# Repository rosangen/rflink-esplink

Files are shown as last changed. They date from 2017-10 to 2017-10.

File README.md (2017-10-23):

RFLink-ESPLink pcb
===================

This is a PCB card for use with [RFLink](http://rflink.nl/blog2/) software, [ESP-Link](https://github.com/jeelabs/esp-link), [ESP-Easy](https://github.com/letscontrolit/ESPEasy) or what you find fits you best.
It is mainly for my purpose of getting [IKEA anslut remote control](http://www.ikea.com/se/sv/catalog/products/90300773/) in my Home Assistant setup. And for measure my pellets and power meter.

**You can fill the board so it meat yours need!!**

Use it as a RFLink with receiver and transmitter, and connect to server with USB, add CC2500 module for IKEA asnlut support.

Add a Wemos D1 Mini to get the RFLink more portable and communicate via WiFi via [tcp-mode](https://home-assistant.io/components/rflink/#tcp-mode).
If you just are interested in IKEA anslut, use a CC2500 module + Arduino Pro Mini + Wemos D1 Mini and communicate with MQTT.
 
Inspired by https://github.com/NDBCK/Ansluta-Remote-Controller for Arduino Pro Mini support, and also https://github.com/Genestealer/Home-Assistant-RFLink-Gateway-ESP8266 fore the komplete setup!

Schema
-----------
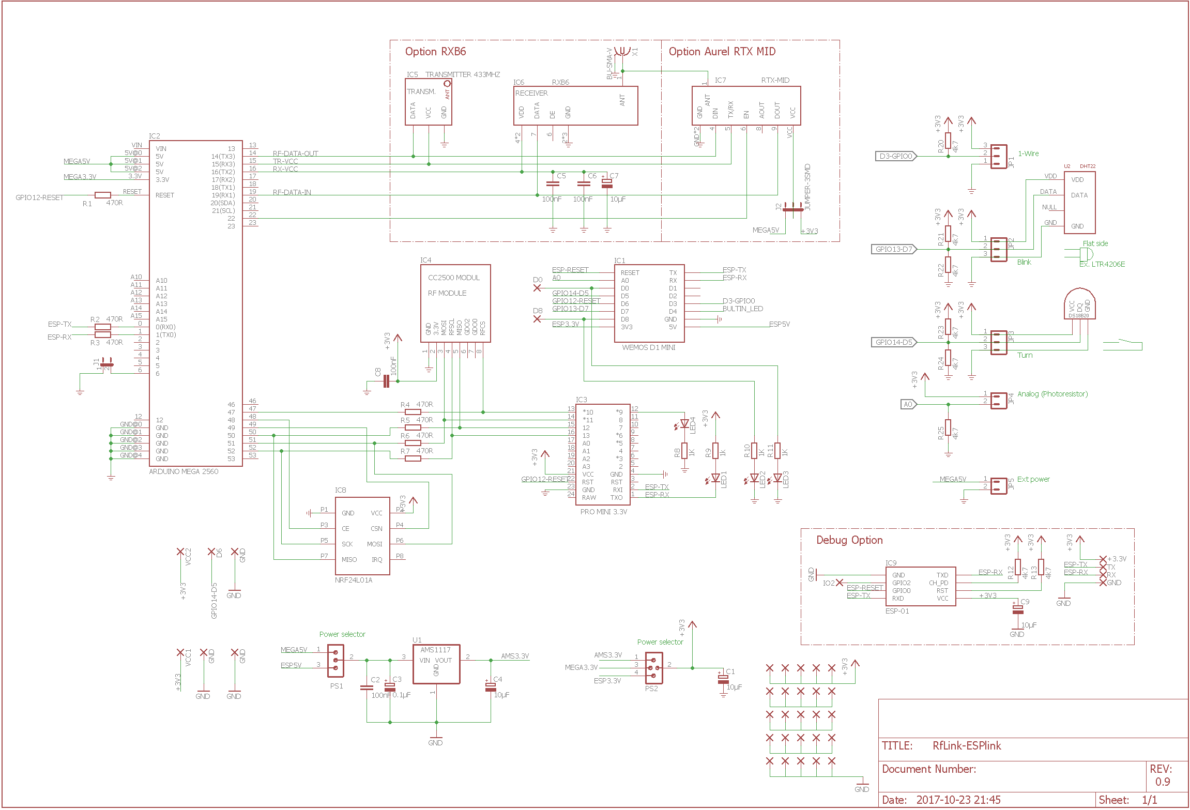
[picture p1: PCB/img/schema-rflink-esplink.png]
rflink-esplink schema Schema img

[Schema pdf](https://github.com/rosangen/rflink-esplink/blob/master/PCB/RfLink-ESPlink.pdf?raw=true "RfLink-ESPlink.pdf")

PCB
------
Size 94 x 96mm
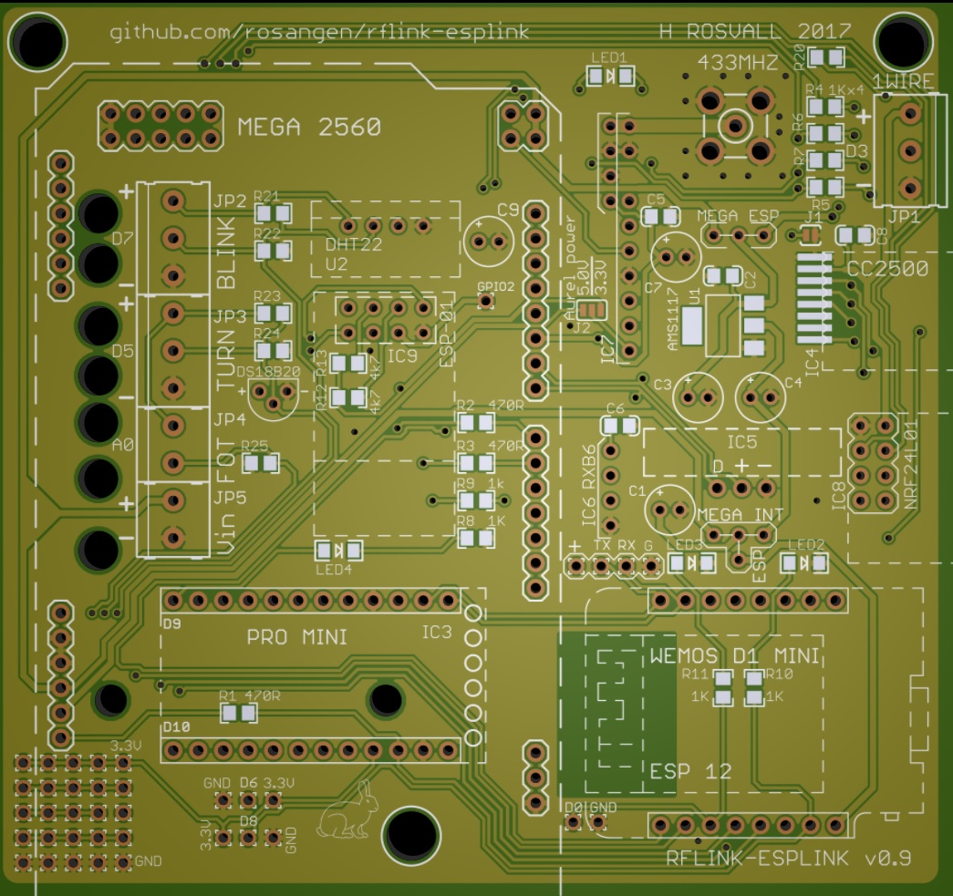
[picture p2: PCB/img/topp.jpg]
rflink-esplink pcb topside


Fore the moment, no PCB is tested, more info to come!

Configurations
-----------
Some configurations explained:

### RFLink USB connected:
```
IC2 Arduino Mega, IC5 Transmitter, IC6 or IC7 Receiver, X1 Antenna connection. 
Option 1: C5,C6 and C7 for better reception with RXB6 receiver.
Option 2: R3, R9, LED1 so se TX communication is visible (receiving data).
```

### RFLink with ESP-link:
```
IC1 ESP, IC2 Arduino Mega, IC5 Transmitter, IC6 or IC7 Receiver. R1, R2, R3.
- Ansluta option: IC4 CC2500, R4-7, C8.
- Option 1 and 2, se above.
```

### Anluta MQTT:
```
IC1 ESP, IC3 Arduino Pro Mini 3.3v, IC4 CC2500 modul, C8.
- Option R9 LED1
```

### EasyESP:
With 1-wire temp and power meter sensor.
```
IC1 ESP, R20-R25 if needed. If lead needed: R10, R11, LED 2, LED3, R20, JP1, R21, JP2. 
Temperatur: DS18B20 connected to JP1
Power meter: LTR4206E ir detector connected to JP2.
```

### Onboard 3.3v converter
If you don't want to use Mega 2560 or ESP interna 3.3v converter you can add U1 (AMS1117 3.3v) and C2, C3, C4.
- PS1 Power selector is for choose input source, IC2 Mega or IC1 ESP 5 volt. (JP5 can only be in used if not Mega 2560 is in use).
- PS2 is the 3.3v source selector, use INT with interna 3.3v converter.

Komponents
-----------

<table>
<tbody>
<tr>
<td><strong>Part</strong></td>
<td><strong>Value</strong></td>
<td><strong>Device/Type</strong></td>
<td><strong>Package/Info</strong></td>
</tr>
<tr>
<td>C1</td>
<td>10&micro;F</td>
<td>CAPACITOR</td>
<td>E2-5</td>
</tr>
<tr>
<td>C2</td>
<td>100nF</td>
<td>CAPACITOR</td>
<td>C0805</td>
</tr>
<tr>
<td>C3</td>
<td>0.1&micro;F</td>
<td>CAPACITOR</td>
<td>E2-5</td>
</tr>
<tr>
<td>C4</td>
<td>10&micro;F</td>
<td>CAPACITOR</td>
<td>E2-5</td>
</tr>
<tr>
<td>C5</td>
<td>100nF</td>
<td>CAPACITOR</td>
<td>C0805</td>
</tr>
<tr>
<td>C6</td>
<td>100nF</td>
<td>CAPACITOR</td>
<td>C0805</td>
</tr>
<tr>
<td>C7</td>
<td>10&micro;F</td>
<td>CPOL-EUE2-5</td>
<td>E2-5</td>
</tr>
<tr>
<td>C8</td>
<td>100nF</td>
<td>CAPACITOR</td>
<td>C0805</td>
</tr>
<tr>
<td>C9</td>
<td>10&micro;F</td>
<td>CPOL-EUE2-5</td>
<td>E2-5</td>
</tr>
<tr>
<td>IC1</td>
<td>WEMOS D1 MINI</td>
<td>WEMOS D1 MINI</td>
<td>&nbsp;WeMos.cc</td>
</tr>
<tr>
<td>IC2</td>
<td>ARDUINO-MEGA</td>
<td>ARDUINO MEGA 2560</td>
</tr>
<tr>
<td>IC3</td>
<td>PRO MINI 3.3V</td>
<td>ARDUINO PRO MINI</td>
</tr>
<tr>
<td>IC4</td>
<td>CC2500</td>
<td>CC2500 MODULE</td>
</tr>
<tr>
<td>IC5</td>
<td>TRANSMITTER 433MHZ</td>
<td>TRANSMITTER 433MHZ</td>
</tr>
<tr>
<td>IC6</td>
<td>RXB6</td>
<td>RECEIVER</td>
</tr>
<tr>
<td>IC7</td>
<td>RTX-MID</td>
<td>RTX-MID</td>
<td>Aurel</td>
</tr>
<tr>
<td>IC8</td>
<td>NRF24L01A</td>
<td>NRF24L01A</td>
<td>NRF24L01</td>
</tr>
<tr>
<td>IC9</td>
<td>ESP-01</td>
<td>ESP8266 Wifi module 01</td>
</tr>
<tr>
<td>J1</td>
<td>JUMPER 2 SMD</td>
<td>Jumper</td>
<td>Aktivate CC2500</td>
</tr>
<tr>
<td>J2</td>
<td>JUMPER 3 SMD</td>
<td>Jumper</td>
<td>3.3 or 5.0V Aurel</td>
</tr>
<tr>
<td>JP1</td>
<td>GS015S-3.81-3P</td>
<td>PCB terminal block</td>
<td>PCB terminal block</td>
</tr>
<tr>
<td>JP2</td>
<td>GS015S-3.81-3P</td>
<td>PCB terminal block</td>
<td>PCB terminal block</td>
</tr>
<tr>
<td>JP3</td>
<td>GS015S-3.81-3P</td>
<td>PCB terminal block</td>
<td>PCB terminal block</td>
</tr>
<tr>
<td>JP4</td>
<td>GS015S-3.81-2P</td>
<td>PCB terminal block</td>
<td>PCB terminal block</td>
</tr>
<tr>
<td>JP5</td>
<td>GS015S-3.81-2P</td>
<td>PCB terminal block</td>
<td>PCB terminal block</td>
</tr>
<tr>
<td>LED1</td>
<td>LED1206</td>
<td>LED-1206</td>
<td>LEDs</td>
</tr>
<tr>
<td>LED2</td>
<td>LED1206</td>
<td>LED-1206</td>
<td>LEDs</td>
</tr>
<tr>
<td>LED3</td>
<td>LED1206</td>
<td>LED-1206</td>
<td>LEDs</td>
</tr>
<tr>
<td>LED4</td>
<td>LED1206</td>
<td>LED-1206</td>
<td>LEDs</td>
</tr>
<tr>
<td>PS1</td>
<td>JUMPER</td>
<td>2 TO 1 POWER</td>
</tr>
<tr>
<td>PS2</td>
<td>JUMPER</td>
<td>3 TO 1 POWER</td>
</tr>
<tr>
<td>R1</td>
<td>470R</td>
<td>RESISTOR R0805</td>
<td>R0805</td>
</tr>
<tr>
<td>R2</td>
<td>470R</td>
<td>RESISTORR0805</td>
<td>R0805</td>
</tr>
<tr>
<td>R3</td>
<td>470R</td>
<td>RESISTORR0805</td>
<td>R0805</td>
</tr>
<tr>
<td>R4</td>
<td>470R</td>
<td>RESISTORR0805</td>
<td>R0805</td>
</tr>
<tr>
<td>R5</td>
<td>470R</td>
<td>RESISTORR0805</td>
<td>R0805</td>
</tr>
<tr>
<td>R6</td>
<td>470R</td>
<td>RESISTORR0805</td>
<td>R0805</td>
</tr>
<tr>
<td>R7</td>
<td>470R</td>
<td>RESISTORR0805</td>
<td>R0805</td>
</tr>
<tr>
<td>R8</td>
<td>1K</td>
<td>RESISTORR0805</td>
<td>R0805</td>
</tr>
<tr>
<td>R9</td>
<td>1K</td>
<td>RESISTORR0805</td>
<td>R0805</td>
</tr>
<tr>
<td>R10</td>
<td>1K</td>
<td>RESISTORR0805</td>
<td>R0805</td>
</tr>
<tr>
<td>R11</td>
<td>1K</td>
<td>RESISTORR0805</td>
<td>R0805</td>
</tr>
<tr>
<td>R12</td>
<td>4k7</td>
<td>RESISTORR0805</td>
<td>R0805</td>
</tr>
<tr>
<td>R13</td>
<td>4k7</td>
<td>RESISTORR0805</td>
<td>R0805</td>
</tr>
<tr>
<td>R20</td>
<td>4k7</td>
<td>RESISTORR0805</td>
<td>R0805</td>
</tr>
<tr>
<td>R21</td>
<td>4k7</td>
<td>RESISTORR0805</td>
<td>R0805</td>
</tr>
<tr>
<td>R22</td>
<td>4k7</td>
<td>RESISTORR0805</td>
<td>R0805</td>
</tr>
<tr>
<td>R23</td>
<td>4k7</td>
<td>RESISTORR0805</td>
<td>R0805</td>
</tr>
<tr>
<td>R24</td>
<td>4k7</td>
<td>RESISTORR0805</td>
<td>R0805</td>
</tr>
<tr>
<td>R25</td>
<td>4k7</td>
<td>RESISTORR0805</td>
<td>R0805</td>
</tr>
<tr>
<td>U1</td>
<td>AMS1117</td>
<td>800mA and 1A Low Dropout (LDO) Positive Regulator</td>
<td>SOT223</td>
</tr>
<tr>
<td>U2</td>
<td>DHT22</td>
<td>DHT-22</td>
</tr>
<tr>
<td>U3</td>
<td>DS18B20</td>
<td>DS18B20</td>
</tr>
<tr>
<td>X1</td>
<td>BU-SMA-V</td>
<td>ANTEN</td>
</tr>
</tbody>
</table>

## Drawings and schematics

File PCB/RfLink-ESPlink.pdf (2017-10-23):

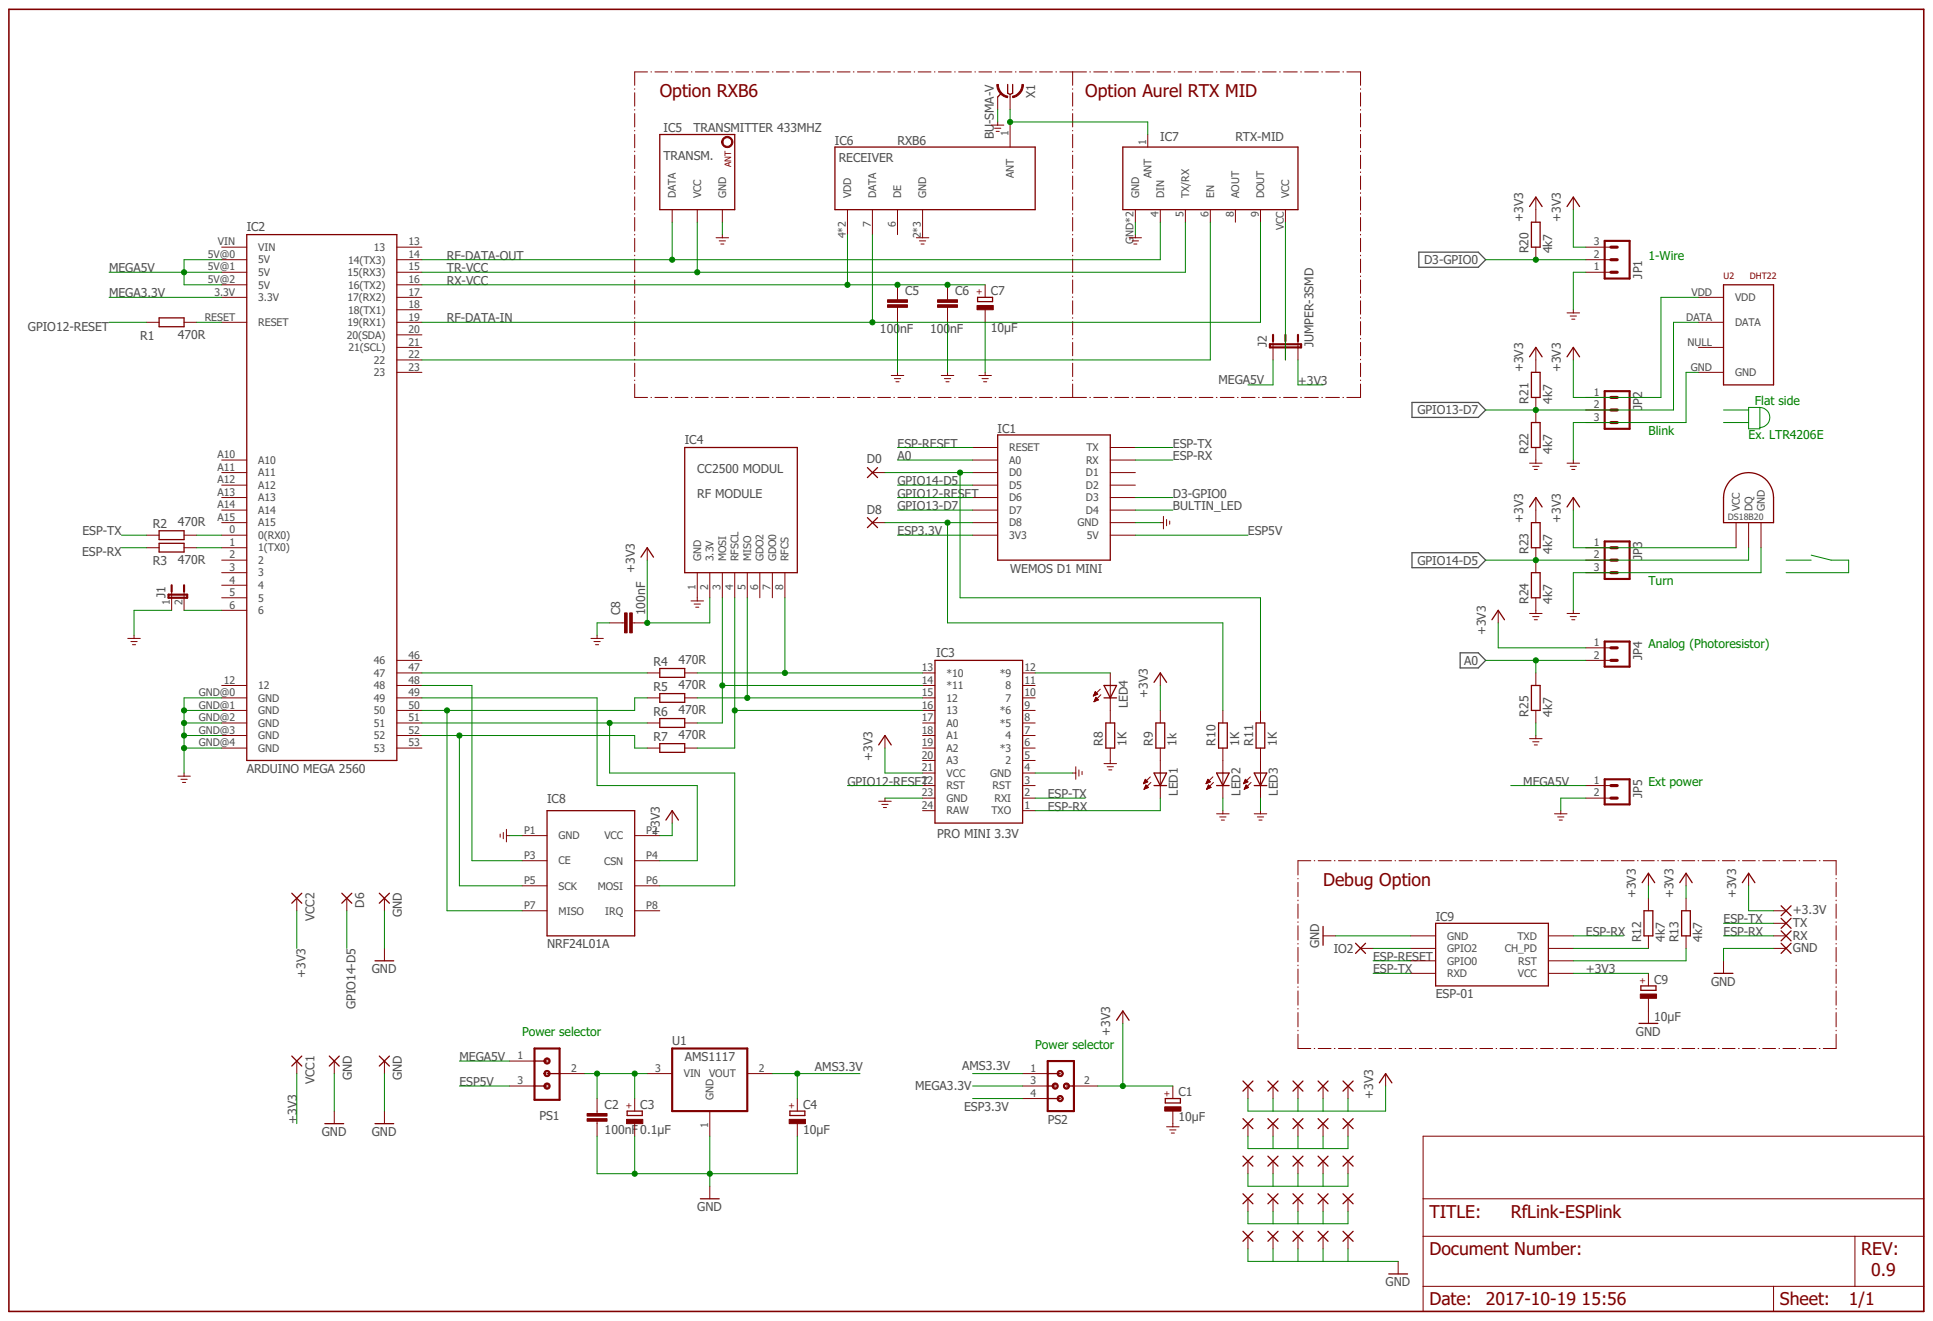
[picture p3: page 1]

TR-VCC RF-DATA-OUT

REV: TITLE: Document Number: RfLink-ESPlink

Date: 2017-10-19 15:56 | Sheet: 1/1

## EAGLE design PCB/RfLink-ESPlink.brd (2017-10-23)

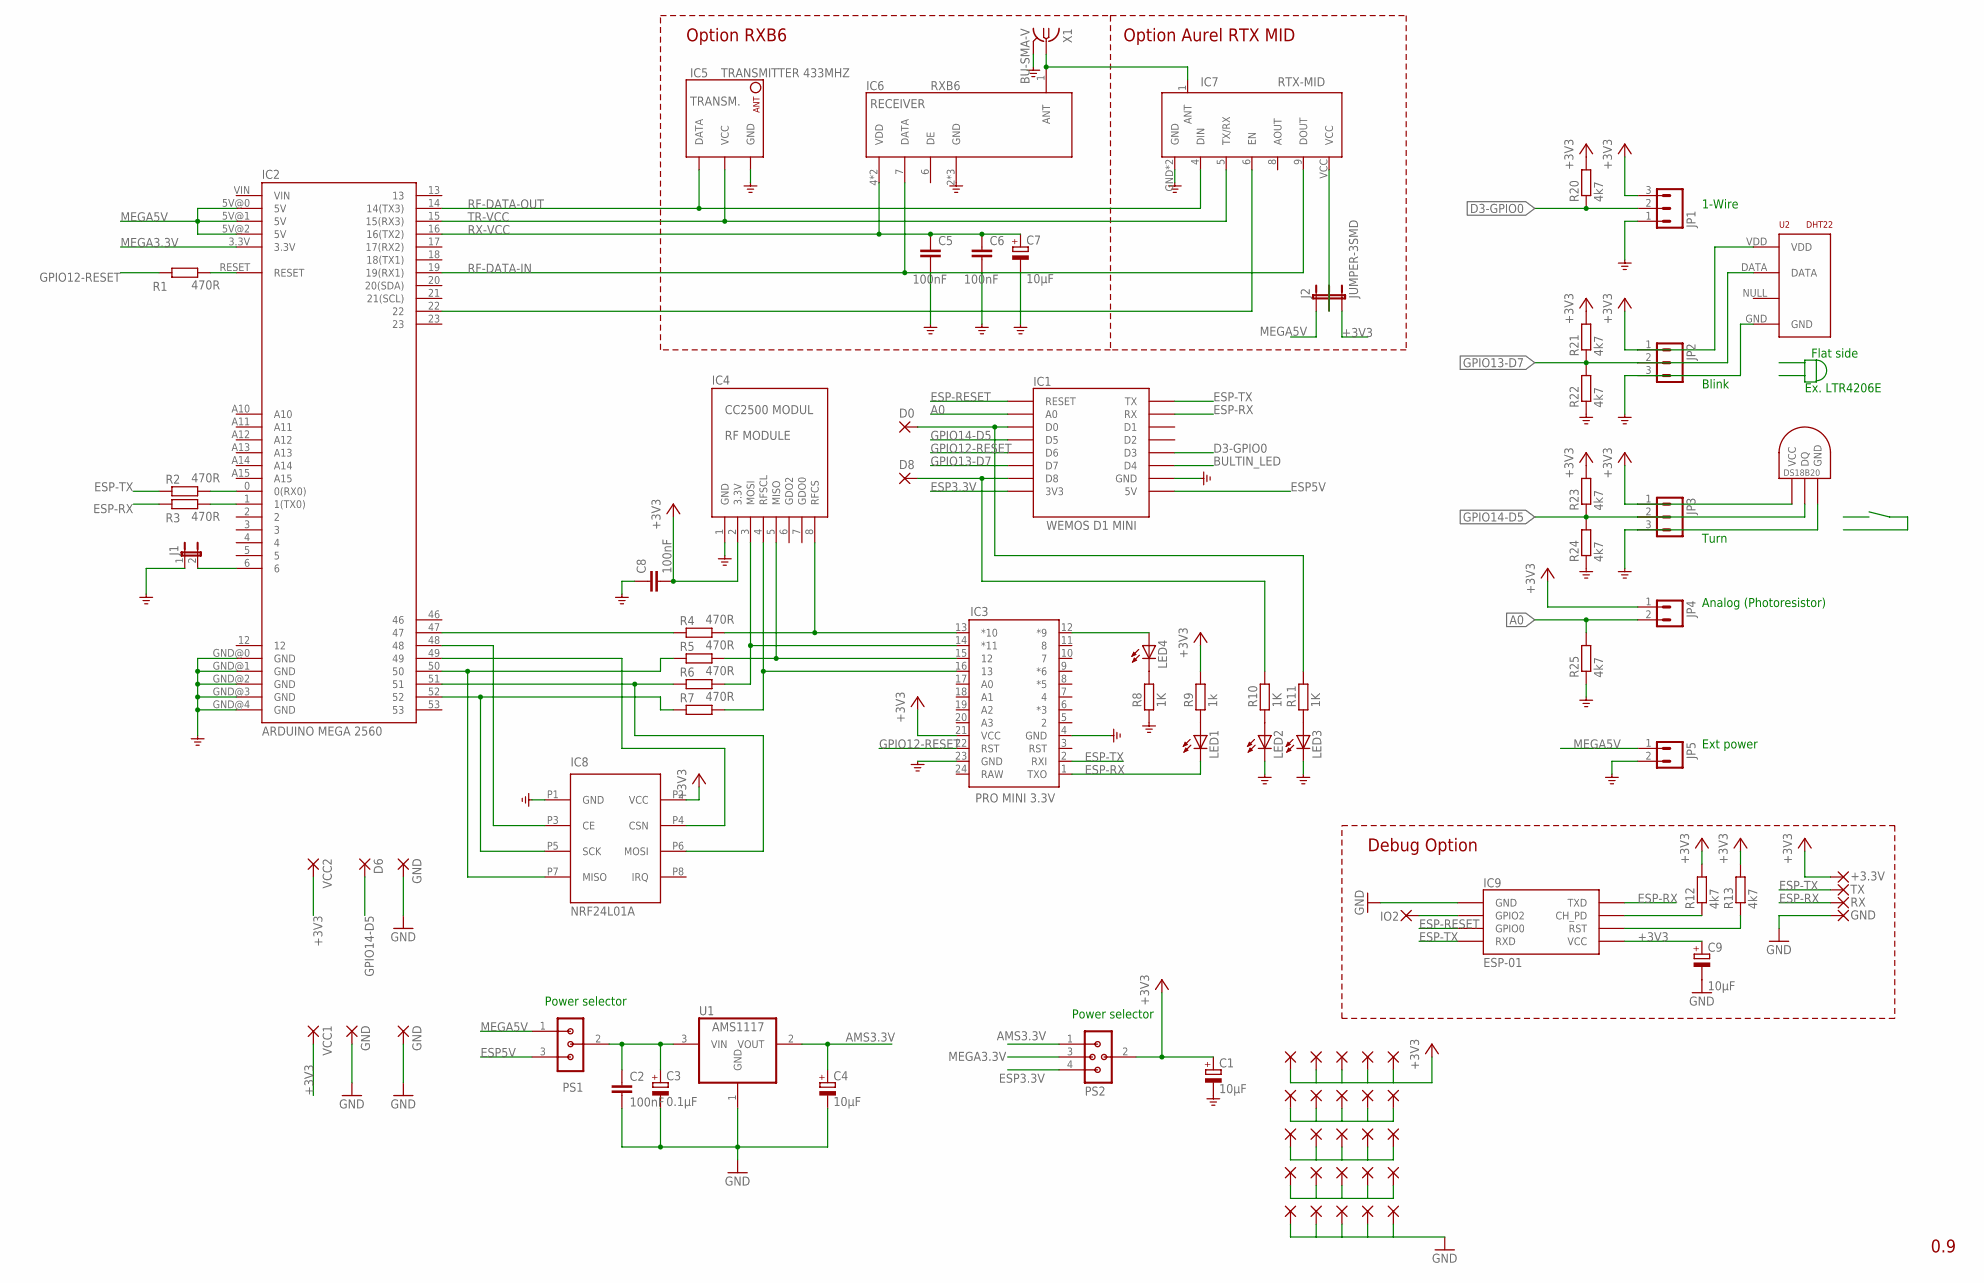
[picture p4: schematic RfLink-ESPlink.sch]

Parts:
+3.3V: 1,6/0,9
C1, C4, C7, C9: 10μF; E2-5
C2, C5, C6, C8: 100nF; C0805
C3: 0.1μF; E2-5
D0, D8: 1,6/0,9
D6: D6; 1,6/0,9
G: GND; 1,6/0,9
GND, GND5, GND7: GND; 1,6/0,9
GPIO2: IO2; 1,6/0,9
IC1: WEMOS D1 MINI; WEMOS-D1-MINI
IC2: ARDUINO MEGA 2560; ARDUINO_MEGA_MINI
IC3: PRO MINI 3.3V; ARDUINO_PRO_MINI
IC4: CC2500 MODUL; CC2500
IC5: TRANSMITTER 433MHZ; TRANSMITTER433MHZ
IC6: RXB6; RXB6-LOW-SILKSCREEN
IC7: RTX-MID
IC8: NRF24L01A; NRF24L01
IC9: ESP-01; ESP01
J1: JUMPER-2SMD-NO; SJ_2S-NO
J2: JUMPER-3SMD; SJ_3
JP1, JP2, JP3: GS015S-3.81-3P; GS015S-3.81-3
JP4, JP5: GS015S-3.81-2P; GS015S-3.81-2
LED1, LED2, LED3, LED4: LED1206; LED-1206
P1, P2, P3, P4, P5, P6, P7, P8, P9, P10, P11, P12, P13, P14, P15, P16, P17, P18, P19, P20, P21, P22, P23, P24, P25: 1,6/0,9
PS1: SV2; 2-1
PS2: 3TO1POWER; 3-1
R1, R2, R3, R4, R5, R6, R7: 470R; R0805
R8, R10, R11: 1K; R0805
R9: 1k; R0805
R12, R13, R20, R21, R22, R23, R24, R25: 4k7; R0805
RX: RX; 1,6/0,9
TX: TX; 1,6/0,9
U1: AMS1117; SOT223
U2: DHT22; RHT03_DHT-22
U3: DS18B20; DS1820
VCC1, VCC2: 1,6/0,9
X1: BU-SMA-V

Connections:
+3V3: +3.3V.1, C1.+, C8.2, C9.+, IC3.21 (VCC), IC4.2 (3.3V), IC8.P2 (VCC), IC9.VCC, J2.3, JP1.3, JP2.1, JP3.1, JP4.1, P21.1, P22.1, P23.1, P24.1, P25.1, PS2.2, R9.2, R12.2, R13.2, R20.2, R21.2, R23.2, U2.VDD, U3.VDD (VCC), VCC1.1, VCC2.1
A0: IC1.A0, JP4.2, R25.2
AMS3.3V: C4.+, PS2.1, U1.2 (VOUT)
ANT: IC6.1 (ANT), IC7.1 (ANT), X1.1
BULTIN_LED: IC1.D4
CC250-ACTIV: IC2.6, J1.2
D3-GPIO0: IC1.D3, JP1.2, R20.1
ESP3.3V: IC1.3V3, PS2.4
ESP5V: IC1.5V, PS1.3
ESP-RESET: IC1.RESET, IC9.GPIO0
ESP-RX: IC1.RX, IC3.1 (TXO), IC9.TX (TXD), LED1.C, R3.1, RX.1
ESP-TX: IC1.TX, IC3.2 (RXI), IC9.RX (RXD), R2.2, TX.1
GND: C1.-, C2.2, C3.-, C4.-, C5.1, C6.1, C7.-, C8.1, C9.-, G.1, GND.1, GND5.1, GND7.1, IC1.GND, IC2.GND@0 (GND), IC2.GND@1 (GND), IC2.GND@2 (GND), IC2.GND@3 (GND), IC2.GND@4 (GND), IC3.4 (GND), IC3.23 (GND), IC4.1 (GND), IC5.P$3 (GND), IC6.2 (GND), IC6.3 (GND), IC6.8 (GND), IC7.GND, IC7.GND1 (GND), IC8.P1 (GND), IC9.GND, J1.1, JP1.1, JP2.3, JP3.3, JP5.2, LED2.C, LED3.C, P11.1, P12.1, P13.1, P14.1, P15.1, R8.1, R22.1, R24.1, R25.1, U1.1 (GND), U2.GND, U3.GND, X1.2, X1.3 (2), X1.4 (2), X1.5 (2)
GPIO12-RESET: IC1.D6, IC3.22 (RST), R1.2
GPIO13-D7: IC1.D7, JP2.2, R21.1, R22.2, U2.DATA
GPIO14-D5: D6.1, IC1.D5, JP3.2, R23.1, R24.2, U3.DQ
MEGA3.3V: IC2.3.3V, PS2.3
MEGA5V: IC2.5V@0 (5V), IC2.5V@1 (5V), IC2.5V@2 (5V), J2.1, JP5.1, PS1.1
MEGA-RX: IC2.0 (0(RX0)), R2.1
MEGA-TX: IC2.1 (1(TX0)), R3.2
unnamed: IC2.47, R4.1
unnamed: IC2.50, IC8.P7 (MISO), R5.1
unnamed: IC2.51, IC8.P6 (MOSI), R6.1
unnamed: IC2.52, IC8.P5 (SCK), R7.1
unnamed: LED3.A, R11.1
unnamed: D8.1, IC1.D8, R10.2
unnamed: IC3.14 (*11), IC4.3 (MOSI), R6.2
unnamed: IC2.22, IC7.6 (EN)
unnamed: IC3.16 (13), IC4.4 (RFSCL), R7.2
unnamed: IC3.15 (12), IC4.5 (MISO), R5.2
unnamed: IC3.13 (*10), IC4.8 (RFCS), R4.2
unnamed: IC2.48, IC8.P3 (CE)
unnamed: IC2.49, IC8.P4 (CSN)
unnamed: LED1.A, R9.1
unnamed: LED2.A, R10.1
unnamed: LED4.C, R8.2
unnamed: D0.1, IC1.D0, R11.2
unnamed: IC3.12 (*9), LED4.A
unnamed: C2.1, C3.+, PS1.2, U1.3 (VIN)
unnamed: IC9.CH_PD, R12.1
unnamed: IC7.VCC, J2.2
unnamed: IC9.RST, R13.1
unnamed: GPIO2.1, IC9.GPIO2
unnamed: P1.1, P2.1, P3.1, P4.1, P5.1
unnamed: P6.1, P7.1, P8.1, P9.1, P10.1
unnamed: P16.1, P17.1, P18.1, P19.1, P20.1
RESET: IC2.RESET, R1.1
RF-DATA-IN: IC2.19 (19(RX1)), IC6.7 (DATA), IC7.9 (DOUT)
RF-DATA-OUT: IC2.14 (14(TX3)), IC5.P$1 (DATA), IC7.4 (DIN)
RX-VCC: C5.2, C6.2, C7.+, IC2.16 (16(TX2)), IC6.4 (VDD), IC6.5 (VDD)
TR-VCC: IC2.15 (15(RX3)), IC5.P$2 (VCC), IC7.5 (TX/RX)

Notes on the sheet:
Power selector
Blink
Flat side
Ex. LTR4206E
Analog (Photoresistor)
Turn
1-Wire
Option RXB6
Option Aurel RTX MID
Ext power
0.9
Debug Option

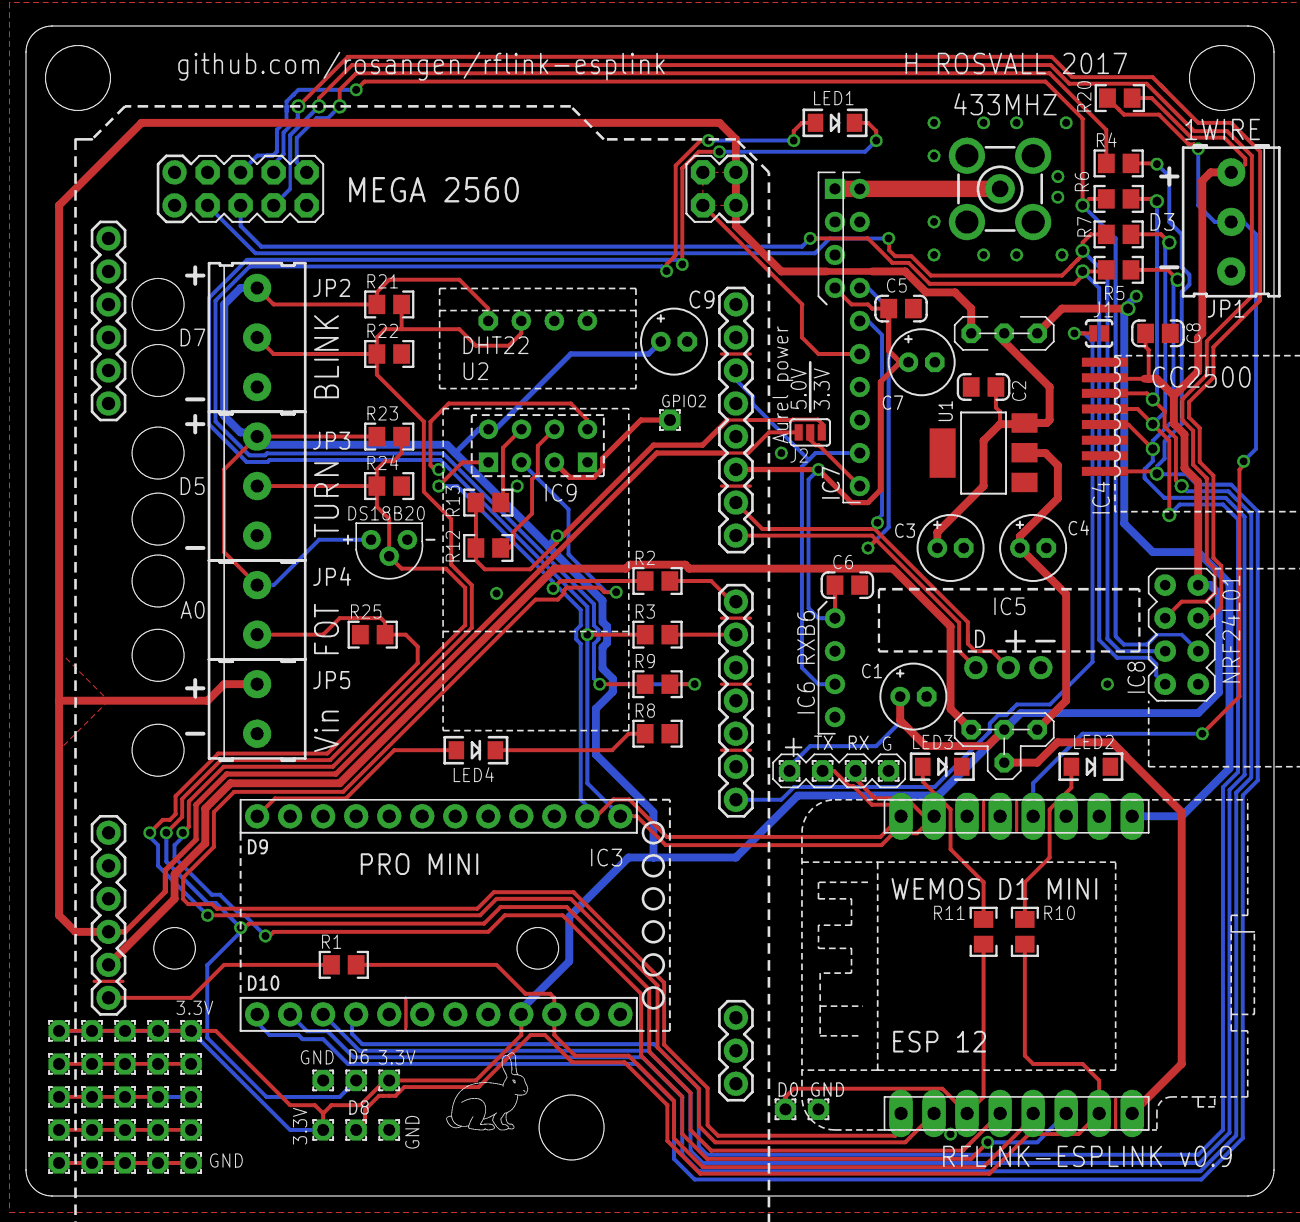
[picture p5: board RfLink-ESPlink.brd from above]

Board: 2 copper layers, 96.0 x 90.0 mm, 93 parts (0 on the bottom side), 50 nets.

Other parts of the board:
U$28: RABBIT-SILK

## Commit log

2017-10-03 Update Schema
    Moved R5 closer to Mega 2560
    [RfLink-ESPlink.brd, RfLink-ESPlink.sch]
2017-10-06 New pcb revison 0.81
    Added resistors to all Arduino Mega 2560 pins connected to ESP, value
    470R. Added JP5 for external power supplt if Mega not are in use.
    Unnecessary pins removed from Mega 2560.
    [RfLink-ESPlink.brd, RfLink-ESPlink.sch]
2017-10-23 New pcb revison 0.9
    Added ESP-01 for easy serial debug of Wemos ESP. This is the
    manufactured version. And some other good to have functions!
    [RfLink-ESPlink.brd, RfLink-ESPlink.sch]

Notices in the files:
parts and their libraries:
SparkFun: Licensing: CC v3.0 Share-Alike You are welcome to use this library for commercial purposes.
